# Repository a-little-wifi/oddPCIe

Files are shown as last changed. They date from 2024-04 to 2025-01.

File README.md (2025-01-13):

# oddPCIe
PCIe + M.2 SATA breakout for Dell Latitude laptop optical drive modular bay

The optical drive (odd) SATA ports on a number of Dell Latitude laptops from 2011-2013 have a PCIe x1 lane hidden in them, meant for use with the AE3USB01 (DP/N P5MKF) USB 3.0 expansion module:  

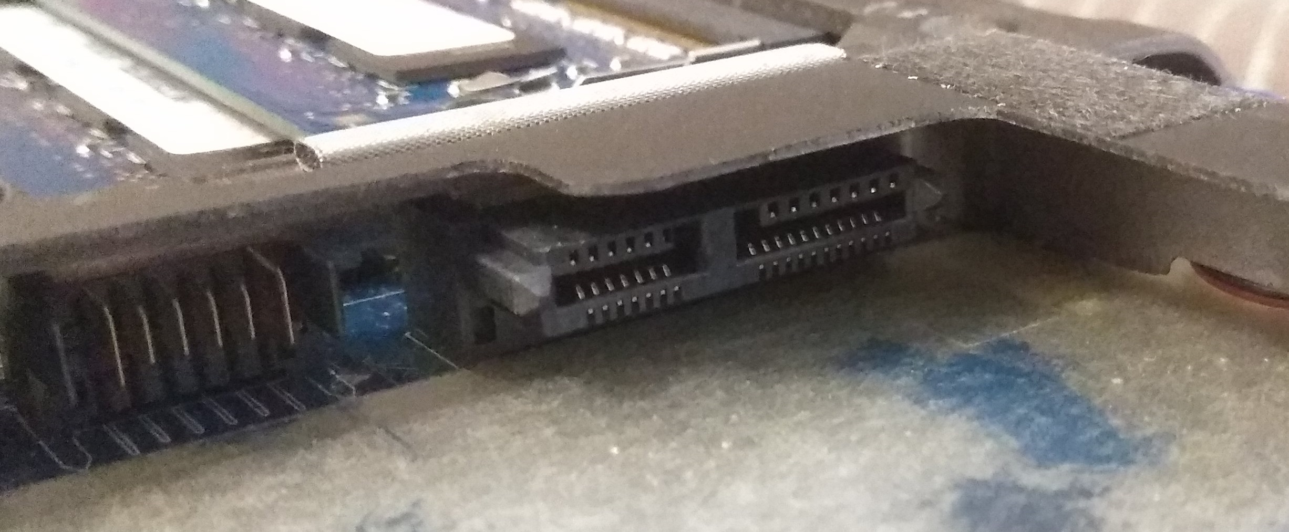
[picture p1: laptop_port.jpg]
> 

> Optical bay port in an E6420, note the second row of pins

## Laptops featuring this port:
* E6320
* E6330 / E6430s
* E6420
* E6430
* E6440
* E6520
* E6530
* E6540 / M2800

Note: The E6440, E6540 and M2800 don't seem to support hot-plug on this PCIe port, as they never actually shipped with anything using this port (the AE3USB01's bezel doesn't even line up with the case)  

## Features:

* PCIe x1 on a USB 3.0 type-a plug compatible with common mining risers
* M.2 SATA SSD slot, since the SATA port is there anyway
* Testpoints for misc pins on the connector

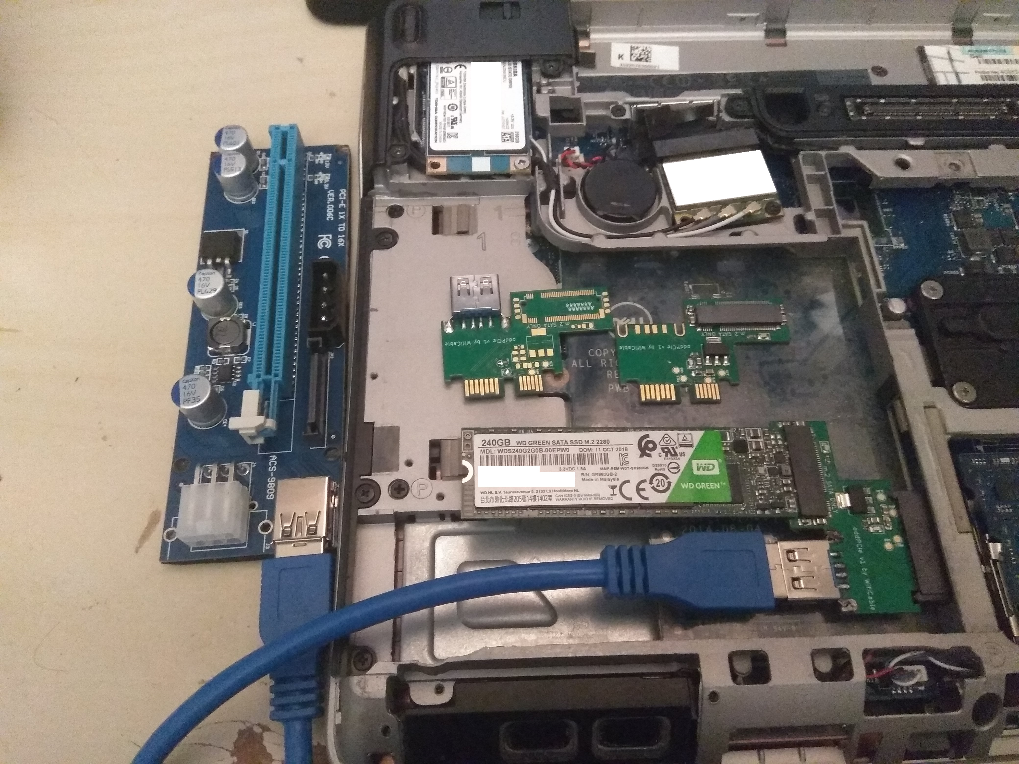
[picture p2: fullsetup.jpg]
> 
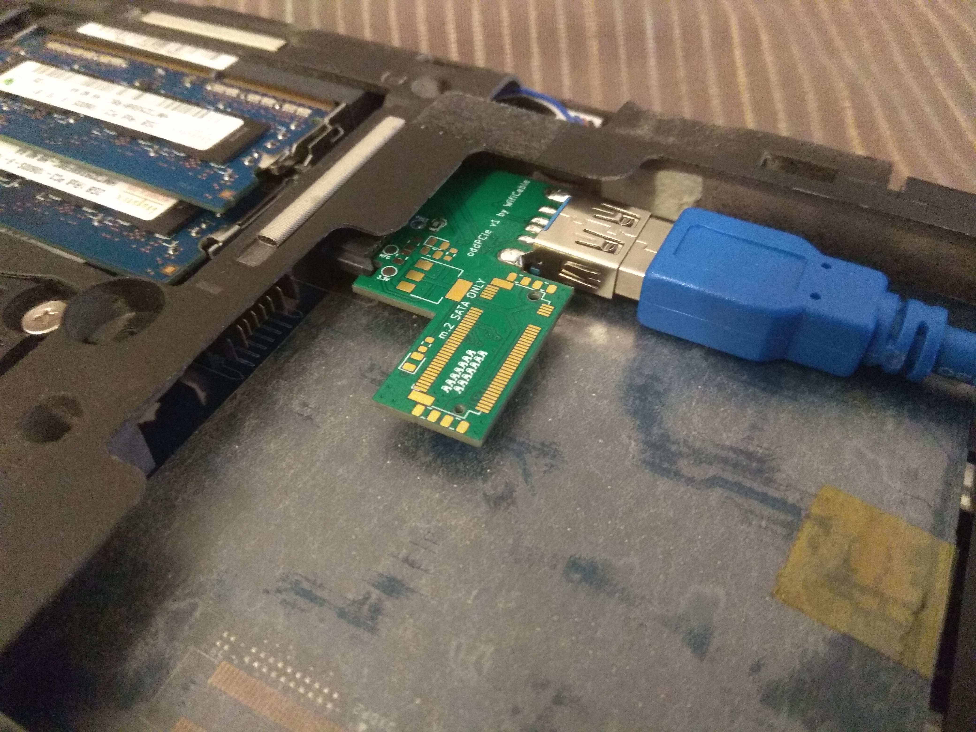
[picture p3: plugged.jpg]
> 

> oddPCIe plugged in to 2 different laptops, showing the fit

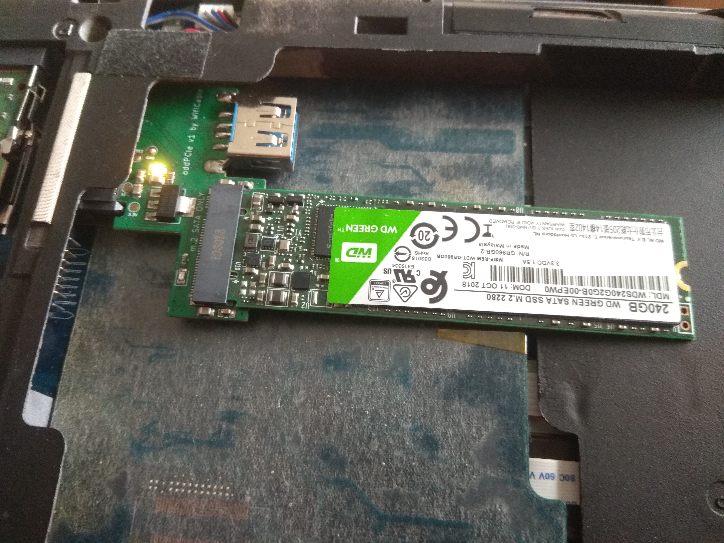
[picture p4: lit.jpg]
> 

> 3.3V regulator power led lighting up

**This board has been manufactured and tested working**  
PCIe port only active if CLKREQ pad is connected to ground  
SATA power only active if PRES pad is connected to ground

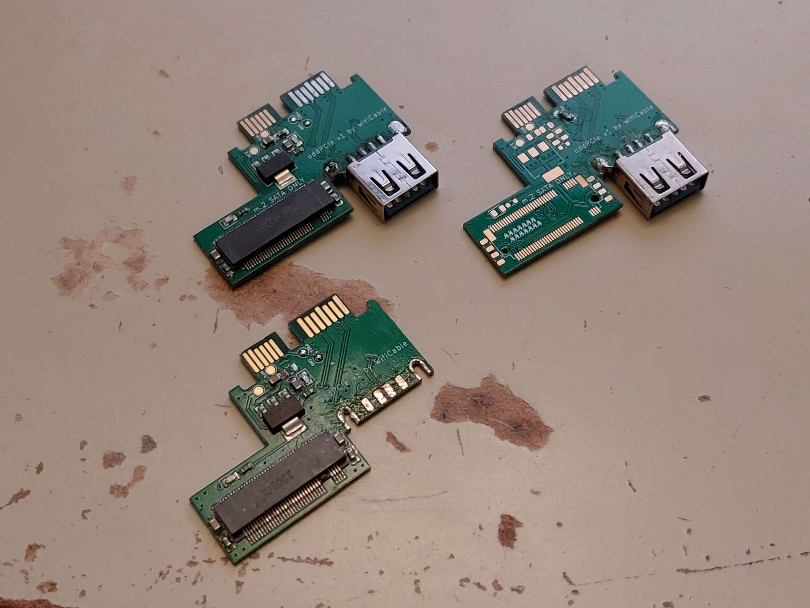
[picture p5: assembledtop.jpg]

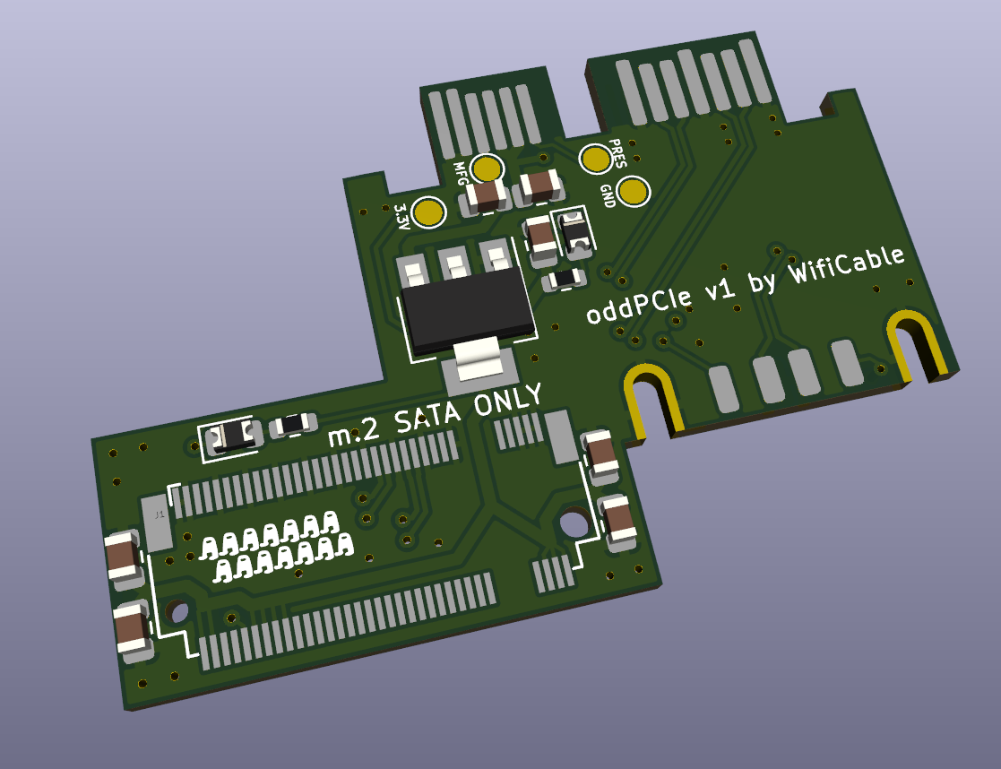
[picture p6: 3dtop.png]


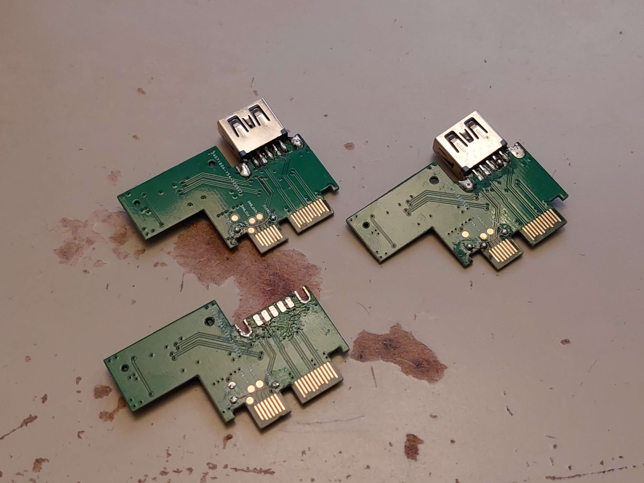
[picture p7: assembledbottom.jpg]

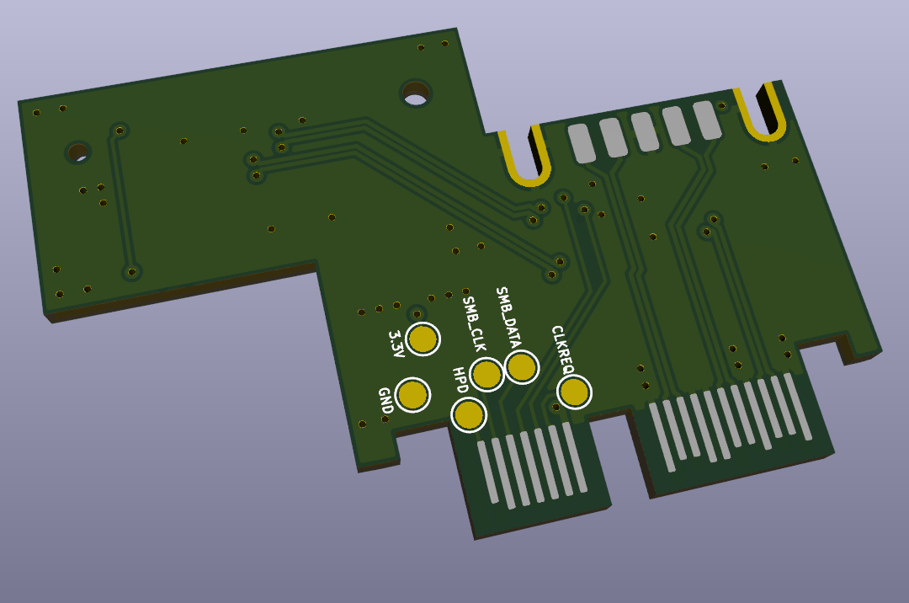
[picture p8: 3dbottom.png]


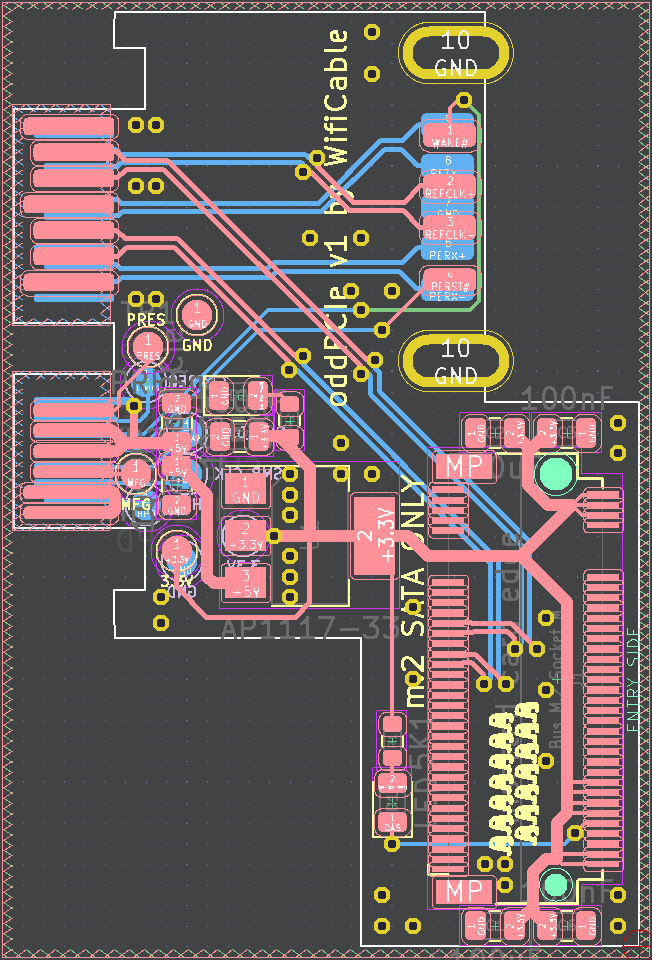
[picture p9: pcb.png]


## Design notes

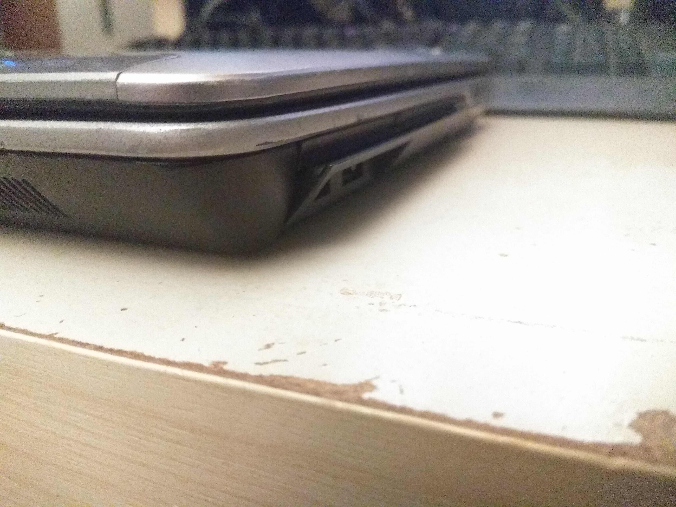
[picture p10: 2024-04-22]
e6440ae3usb01.jpg

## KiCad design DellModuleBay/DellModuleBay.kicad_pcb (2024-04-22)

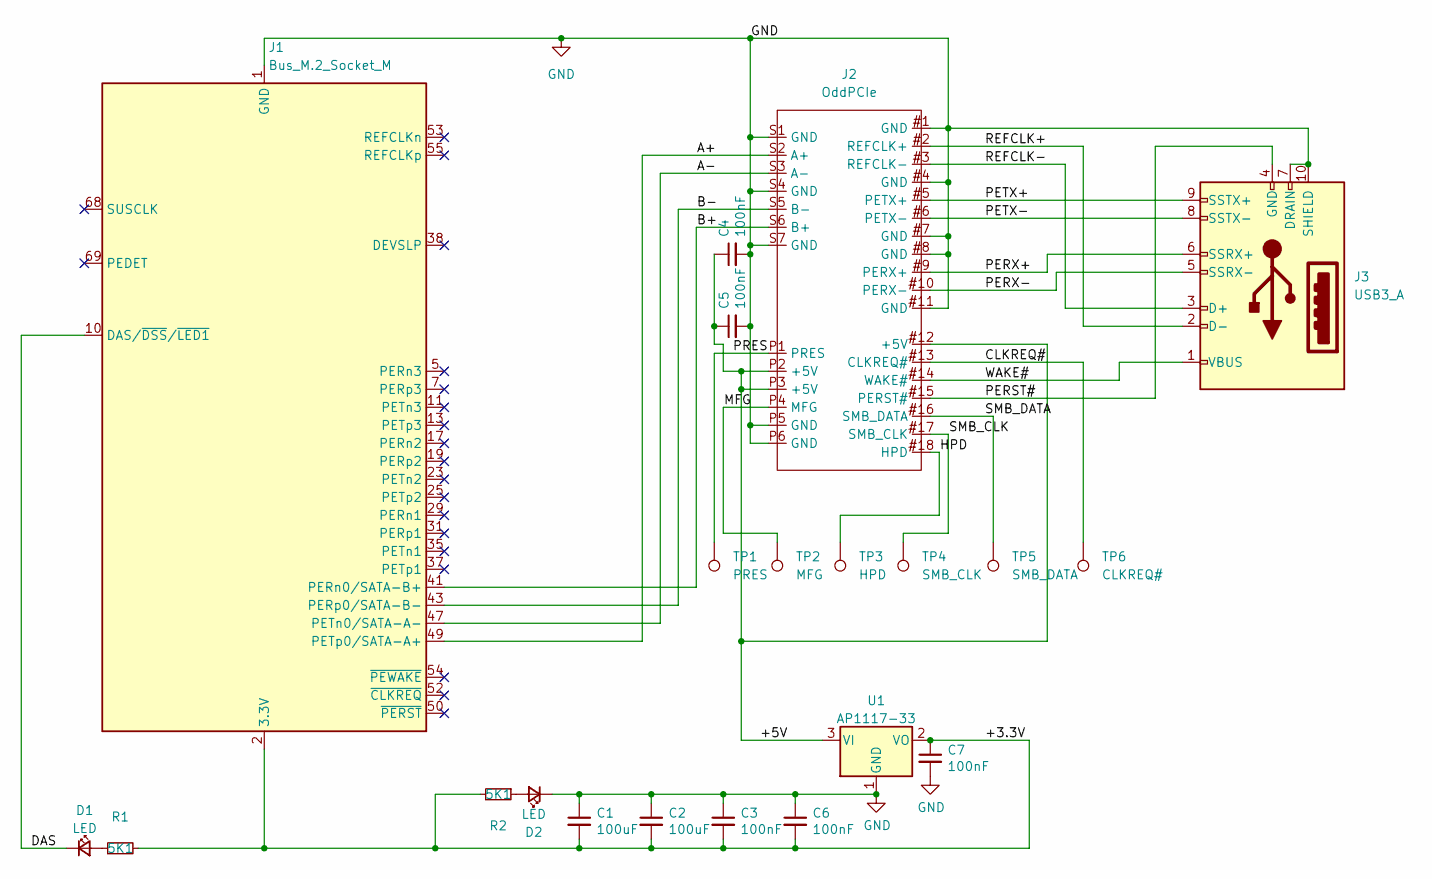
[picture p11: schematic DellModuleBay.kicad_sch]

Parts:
C1, C2: 100uF; C_0805_2012Metric
C3, C4, C5, C6, C7: 100nF; C_0805_2012Metric
D1, D2: LED; D_0805_2012Metric
J1: Bus_M.2_Socket_M; m-key
J2: OddPCIe
J3: USB3_A; susb3
R1, R2: 5K1; R_0603_1608Metric
TP1: PRES; TestPoint_Pad_D1.5mm
TP2: MFG; TestPoint_Pad_D1.5mm
TP3: HPD; TestPoint_Pad_D1.5mm
TP4: SMB_CLK; TestPoint_Pad_D1.5mm
TP5: SMB_DATA; TestPoint_Pad_D1.5mm
TP6: CLKREQ#; TestPoint_Pad_D1.5mm
U1: AP1117-33; SOT-223-3_TabPin2

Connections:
/+3.3V: C1.2, C2.2, C3.2, C6.2, C7.1, J1.2 (3.3V), J1.4 (3.3V), J1.12 (3.3V), J1.14 (3.3V), J1.16 (3.3V), J1.18 (3.3V), J1.70 (3.3V), J1.72 (3.3V), J1.74 (3.3V), R1.2, R2.2, U1.2 (VO)
/+5V: C4.1, C5.1, J2.#12 (+5V), J2.P2 (+5V), J2.P3 (+5V), U1.3 (VI)
/A+: J1.49 (PETp0/SATA-A+), J2.S2 (A+)
/A-: J1.47 (PETn0/SATA-A-), J2.S3 (A-)
/B+: J1.41 (PERn0/SATA-B+), J2.S6 (B+)
/B-: J1.43 (PERp0/SATA-B-), J2.S5 (B-)
/CLKREQ#: J2.#13 (CLKREQ#), TP6.1
/DAS: D1.1 (K), J1.10 (DAS/~DSS/~LED1)
/HPD: J2.#18 (HPD), TP3.1
/MFG: J2.P4 (MFG), TP2.1
/PERST#: J2.#15 (PERST#), J3.4 (GND)
/PERX+: J2.#9 (PERX+), J3.6 (SSRX+)
/PERX-: J2.#10 (PERX-), J3.5 (SSRX-)
/PETX+: J2.#5 (PETX+), J3.9 (SSTX+)
/PETX-: J2.#6 (PETX-), J3.8 (SSTX-)
/PRES: J2.P1 (PRES), TP1.1
/REFCLK+: J2.#2 (REFCLK+), J3.2 (D-)
/REFCLK-: J2.#3 (REFCLK-), J3.3 (D+)
/SMB_CLK: J2.#17 (SMB_CLK), TP4.1
/SMB_DATA: J2.#16 (SMB_DATA), TP5.1
/WAKE#: J2.#14 (WAKE#), J3.1 (VBUS)
GND: C1.1, C2.1, C3.1, C4.2, C5.2, C6.1, C7.2, D2.1 (K), J1.1 (GND), J1.3 (GND), J1.9 (GND), J1.15 (GND), J1.21 (GND), J1.27 (GND), J1.33 (GND), J1.39 (GND), J1.45 (GND), J1.51 (GND), J1.57 (GND), J1.71 (GND), J1.73 (GND), J1.75 (GND), J2.#1 (GND), J2.#4 (GND), J2.#7 (GND), J2.#8 (GND), J2.#11 (GND), J2.P5 (GND), J2.P6 (GND), J2.S1 (GND), J2.S4 (GND), J2.S7 (GND), J3.7 (DRAIN), J3.10 (SHIELD), U1.1 (GND)
unnamed: D1.2 (A), R1.1
unnamed: D2.2 (A), R2.1

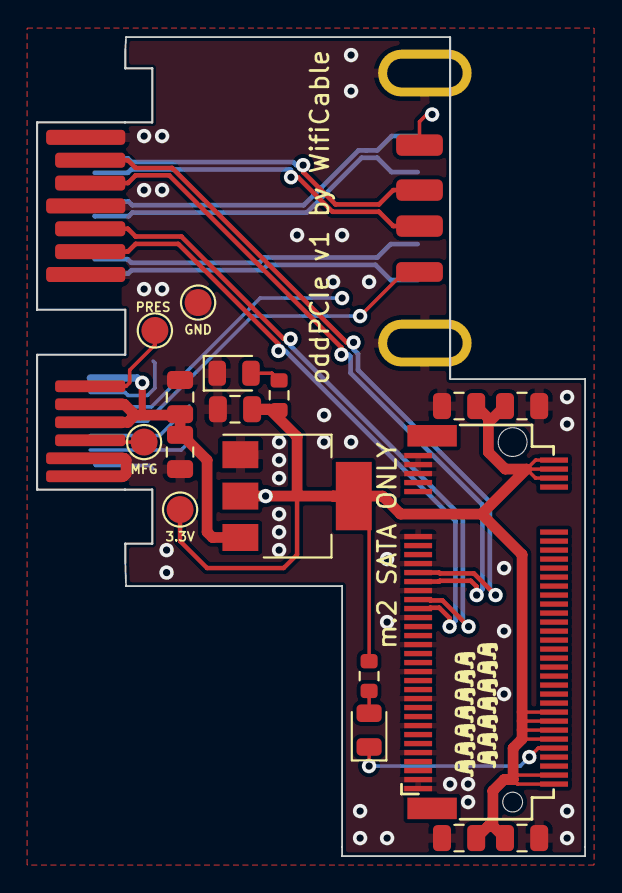
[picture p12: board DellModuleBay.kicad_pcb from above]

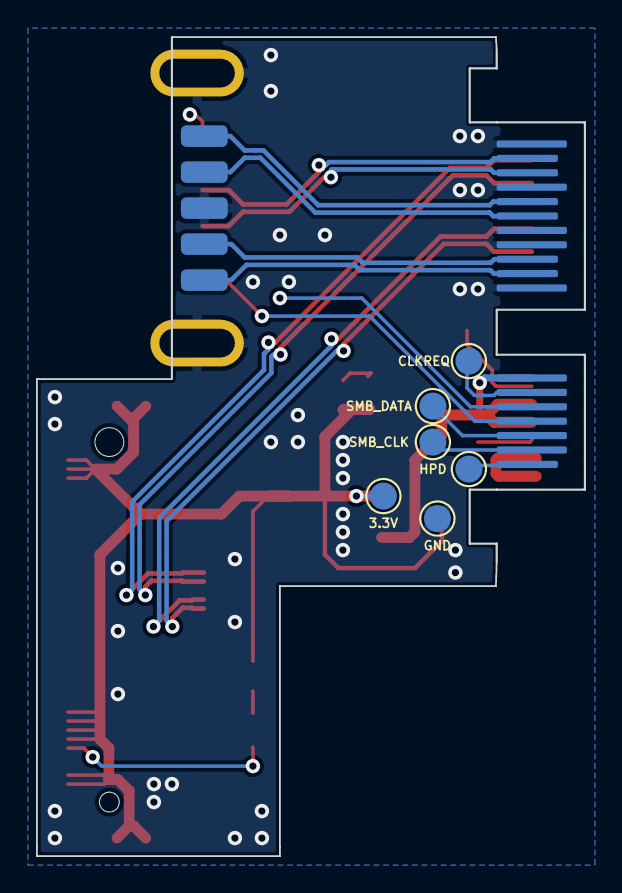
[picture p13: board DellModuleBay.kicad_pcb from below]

Board: 4 copper layers, 30.4 x 45.5 mm, 21 parts (4 on the bottom side), 24 nets.

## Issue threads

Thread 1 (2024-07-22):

Info on trace imp

docop, 2024-07-22:
Hi
 This is a very great projet and very good as i can see clearly the very basic of plugging a unit.. as using only 1 single lane. Very great work. If i may, i wonder.. was it 85ohms impedance match too ? And is having the 2 via made any change or so ?

Thanks in advance

a-little-wifi, 2024-07-25:
Hi,

It's been a while since I made this board, and this was the first board I made with differential signals, but if I remember correctly the traces are indeed impedance matched correctly for the pcb stackup that was used to manufacture them at JLC. The vias shouldn't be much of an issue, as the pairs only go between the outer 2 layers which have the same properties.
And in the end, this board has been tested working, so it gotta be good :D
Are you planning to get some manufactured? I'm glad to hear this project is useful to someone, I hope it helps you.
